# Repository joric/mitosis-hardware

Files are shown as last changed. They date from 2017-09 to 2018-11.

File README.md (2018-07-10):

Kicad Mitosis
=============

A port of original Mitosis converted with [altium2kicad](https://github.com/thesourcerer8/altium2kicad).

Disclaimer
----------

* hanya - files taken from [here](https://github.com/hanya/mitosis-hardware/tree/kicad) (with a working net), this is the most accurate
* default - cleaned up autoconverted version, should be ready for export
* big-pads - wider pads for YJ-14015 (still a bit unfinished check pads carefully!)
* autoconverted - raw autoconverted board (misplaced labels, messed up outlines, etc.)
* interphase - KiCad files taken from [here](https://github.com/Durburz/interphase) (Mitosis with a little bit more keys), see [reddit][interphase]
* orthrus - KiCad files taken from [here](https://github.com/bezmi/orthrus) (great Atreus62/Mitosis crossover by bezmi), see [reddit][orthrus]

Converting
----------

Apply .pl scripts then delete all unnecessary Edge.Cuts (such as 10x10 cm outline).

Remove board outline from Dwgs.User.

All footprint texts made invisible ("Switch", "NRF51822", etc. - they weren't in the gerbers).

Battery footprint and mitosis branding will appear misplaced, so move them down.

Check results in 3D viewer against the original gerber.

Editing
-------

To make bigger nrf51 pads, use select - Edit All Pads, set width to 2.5 mm and apply for all.

Exporting
---------

Use File-Plot command to export gerber files.

Check F.Cu, B.Cu, B.Paste, F.Paste, B.Silk, F.Silk and the Edge.Cuts layers, and also Dwgs.User.

Do not check Exclude PCB edge layer from other layers.

Then export Drill file, use Gerber in the Format section and check Minimal header.

References
----------

* [Acrylic case friendly mod (Altium)](https://github.com/YCF/mitosis-hardware-mod)
* [Hanya's port with a working net (KiCad)](https://github.com/hanya/mitosis-hardware)
* [A mod with battery between the switches (video)](https://www.reddit.com/r/MechanicalKeyboards/comments/6tcctx/new_buildmitosisplusthank_you_reverse_bias/dlk3rg7/)
* [Interphase mod with more keys](https://github.com/Durburz/interphase)
* [Orthrus - wireless split, 56 keys, based on Mitosis and Atreus](https://github.com/bezmi/orthrus)

[orthrus]: https://www.reddit.com/r/MechanicalKeyboards/comments/8txry7/orthrus_wireless_split_56_keys_based_on_mitosis
[interphase]: https://www.reddit.com/r/MechanicalKeyboards/comments/7ggeww/photos_interphase_finished_my_prototype/

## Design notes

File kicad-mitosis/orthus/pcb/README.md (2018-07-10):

# PCB

PCB design files and gerbers for the orthrus keyboard. See the [mitosis build log](https://imgur.com/a/mwTFj#JtzXTCD) for an overview of how to put this together.

There are a couple of minor differences. For example, for the programming header, my right angle connector footprint is too far in from the edge of the PCB, which resulted in the particular right angle headers I had not being reachable. I compromised by just using straight headers that go through the holes in the top (switch plate) pcb. It works just fine and the header is optional anyway. You could just as well solder temporary wires, program, then desolder before final assembly.

For the foam base, I did not have access to a lasercutter, so I cut a cloth mouse pad to size (including a cutout for the module on the bottom), cut all of the switch pins flush to the bottom of the PCB and hot glued the mousepad bits to the bottom. It is a little bumpy if you feel the bottom of the keyboard, but the typing feel is not compromised. Make sure you put tape on the module to avoid shorts!

For the receiver, I use the [mitosis receiver PCB](https://github.com/reversebias/mitosis-hardware). You can look at the BOM there (adjusting for extra switches, etc). I designed the PCBs to use the cheaper black nrf modules from aliexpress (Yj-14015), which are slightly smaller than the official waveshare module. For the receiver I had a legitimate waveshare module (blue) laying around, so I just used that, but soldering a Yj-14015 module to the receiver PCB can be very tricky. Feel free to extend the mitosis receiver pads and submit a pull request.

Make sure the PCB fab house can do 0.8mm slots. I've got mine manufactured from JLCPCB and the PCBs came out perfect.

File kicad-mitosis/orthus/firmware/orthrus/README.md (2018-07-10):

# Mitosis Keyboard Firmware

This branch adds YJ-14015 and IAR support.

mitosis-mjt (https://www.youtube.com/watch?v=hMlQvZNmCc8)

It also makes use of the keyswitch board LED (it blinks two times on powering up to indicate that firmware works).

I'm using [modified QMK firmware](https://github.com/joric/qmk_firmware/blob/mitosis-joric/keyboards/mitosis/mitosis.c) (with mitosis-MJT keymap) that adds LED startup sequence to the receiver as well.

## Hardware

* [ST-LINK/V2](http://www.ebay.com/itm/ST-Link-V2-Programming-Unit-mini-STM8-STM32-Emulator-Downloader-M89-Top-/331803020521) (OpenOCD-compatible debugger/programmer)
* [YJ-14015](https://www.aliexpress.com/item/Core51822-BLE-4-0-Bluetooth-2-4G-Wireless-Module-NRF51822-Antenna-Board-For-ULP-SPI-I2C/32832872640.html) (nRF51822-module, 32-bit ARM Cortex M0, 128kB flash + 32kB RAM)
* PCB gerbers I used in this build: https://github.com/reversebias/mitosis-hardware

I've also collected a few Kicad ports from Altium: https://github.com/joric/mitosis-hardware/tree/joric_kicad

## Software

* [IAR 7.50.2 for ARM](https://www.iar.com/) (IDE that includes a C/C++ compiler)
* [nRF5_SDK_11](https://developer.nordicsemi.com/nRF5_SDK/) (nRF51/52 toolchain)
* [OpenOCD g73b676c](http://www.freddiechopin.info/en/download/category/10-openocd-dev/) (embedded debugger for Windows 10)
* [WinAVR 20100110](https://sourceforge.net/projects/winavr/) (firmware tools for AVR MCU)

## IAR support

Original build used blue Waveshare Core51822 (B)
modules ([$6.99](http://www.waveshare.com/core51822-b.htm)), but aliexpress has slightly smaller black YJ-14015
modules that are also much cheaper (about $3.50), you can find them on Aliexpress or [eBay](http://www.ebay.com/itm/BLE4-0-Bluetooth-2-4GHz-Wireless-Module-NRF51822-Board-Core51822-B-/282575577879).
It seems like stock firmware that works on Core51822 (B), doesn't work on YJ-14015 at all (update, already works, see https://github.com/reversebias/mitosis/pull/7).
You can build a working firmware in IAR, using provided project (open .eww, run build, that's all).
You may also use precompiled firmware from the `precompiled_iar` folder.

## GCC support

This repository now supports GCC for YJ-14015 as well, so there's no need for IAR.
Use GCC-prebuild firmware from the precompiled folder or apply this diff https://github.com/reversebias/mitosis/pull/7
(update: it's already merged into upstream).

## nRF51 Firmware

This firmware is used for the nRF51 modules on the keyboard halves and the receiver.

### Precompiled nRF51 Firmware

This precompiled firmware features YJ-14015 support and status LEDs support.

* left half: [precompiled-basic-left.hex](https://raw.githubusercontent.com/joric/mitosis/devel/precompiled_iar/precompiled-basic-left.hex)
* right half: [precompiled-basic-right.hex](https://raw.githubusercontent.com/joric/mitosis/devel/precompiled_iar/precompiled-basic-right.hex)
* receiver: [precompiled-basic-receiver.hex](https://raw.githubusercontent.com/joric/mitosis/devel/precompiled_iar/precompiled-basic-receiver.hex)

### Uploading nRF51 Firmware

To flash nRF modules, connect ST-LINK/V2 to the module programming pins (SWCLK, SWDIO, GND, 3.3V - top to bottom) and run this batch (windows 10):

```
@echo off
set path=C:\SDK\openocd-0.10.0-dev-00247-g73b676c\bin-x64;%path%
set file=%~dp0custom\iar\_build\nrf51822_xxac.hex
openocd ^
-f interface/stlink-v2.cfg ^
-f target/nrf51.cfg ^
-c init ^
-c "reset halt" ^
-c "flash write_image erase %file:\=/%" ^
-c "reset" ^
-c exit

```

### Building nRF51 Firmware

I am using Windows 10 and Windows Subsystem for Linux (WSL) for everything.

Building nRF firmware with GCC:

```
cd nRF5_SDK_11
git clone https://github.com/joric/mitosis
sudo apt install openocd gcc-arm-none-eabi
(edit /components/toolchain/gcc/Makefile.posix, set GNU_INSTALL_ROOT := /usr/)
sudo cp mitosis/49-stlinkv2.rules /etc/udev/rules.d/
cd mitosis
git checkout devel
cd mitosis-keyboard-basic/custom/armgcc
make

```

## QMK Firmware

This firmware is used for the Arduino Pro Micro on the keyboard receiver.

### Precompiled QMK Firmware

First of all, check [QMK repository](https://github.com/qmk/qmk_firmware/tree/master/keyboards/mitosis/keymaps) maybe your keymap is already merged.

* mitosis-default (original) from /u/reverse_bias: [kle](http://www.keyboard-layout-editor.com/#/gists/f89d2ff79b72e920939b), [keymap.c](https://github.com/qmk/qmk_firmware/blob/master/keyboards/mitosis/keymaps/default/keymap.c), [firmware](https://raw.githubusercontent.com/joric/qmk_firmware/mitosis-joric/precompiled/mitosis_default.hex), [pic](http://i.imgur.com/Ioh0Iix.png)
* mitosis-qwerty (qwerty layout) from /u/runninghack: [kle](http://www.keyboard-layout-editor.com/#/gists/acec41432b5ce0eb341d88245a20d9da), [keymap.c](https://github.com/runninghack/qmk_firmware/blob/master/keyboards/mitosis/keymaps/qwerty/keymap.c), [firmware](https://raw.githubusercontent.com/joric/qmk_firmware/mitosis-joric/precompiled/mitosis_qwerty.hex), [pic](https://i.imgur.com/Jt0lTWt.png)
* mitosis-mjt (qwerty layout) from /u/kaybeerry: [kle](http://www.keyboard-layout-editor.com/#/gists/e213fec721cb035614cef401cd6750d6), [keymap.c](https://github.com/mterhar/qmk_firmware/blob/master/keyboards/mitosis/keymaps/mjt/keymap.c), [firmware](https://raw.githubusercontent.com/joric/qmk_firmware/mitosis-joric/precompiled/mitosis_mjt.hex), [pic](https://i.imgur.com/BiKsnIV.png)
* mitosis-carvac_dv (qwerty layout) by /u/Carvac: [keymap.c](https://github.com/CarVac/qmk_firmware/blob/master/keyboards/mitosis/keymaps/carvac_dv/keymap.c)
* mitosis-workman (workman layout) by /u/mloffer: [kle](http://www.keyboard-layout-editor.com/#/gists/db73d647ad8a67c9654a4daeab0e0873), [keymap.c](https://github.com/mloffer/mitosis-workman)
* mitosis-atreus (atreus layout) from /u/iamjoric: [kle](http://www.keyboard-layout-editor.com/#/gists/e1b26b86c4e024d2f4f3185e5b769a00), [keymap.c](https://github.com/joric/qmk_firmware/blob/mitosis-joric/keyboards/mitosis/keymaps/atreus/keymap.c), [firmware](https://raw.githubusercontent.com/joric/qmk_firmware/mitosis-joric/precompiled/mitosis_atreus.hex)
* mitosis-joric (experimental) from /u/iamjoric: [kle](http://www.keyboard-layout-editor.com/#/gists/3f5dd1c848bb9a7a723161ad5e0c8e39), [keymap.c](https://github.com/joric/qmk_firmware/blob/mitosis-joric/keyboards/mitosis/keymaps/joric/keymap.c), [firmware](https://raw.githubusercontent.com/joric/qmk_firmware/mitosis-joric/precompiled/mitosis_joric.hex)

### Uploading QMK Firmware

To flash prebuilt QMK firmware on Pro Micro, press reset button on the receiver and run the script below.
You can look up the bootloader port in device manager (e.g. COM9), it shows only for a few seconds after reset.

```
set path=C:\WinAVR-20100110\bin;%path%
avrdude -p atmega32u4 -P COM9 -c avr109  -U flash:w:mitosis_default.hex
```

### Building QMK firmware:

```
sudo apt-get install gcc-avr avr-libc
cd qmk_firmware
make mitosis-default
```

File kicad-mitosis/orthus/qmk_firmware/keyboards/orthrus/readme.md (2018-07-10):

Orthrus
=======

Keyboard Maintainer: [@bezmi](https://github.com/bezmi)
Hardware Supported: [Orthrus PCB](https://github.com/bezmi/orthrus)

Make example for this keyboard (run from root qmk_firmware directory)

    make orthrus:default:avrdude

See [build environment setup](https://docs.qmk.fm/build_environment_setup.html) then the [make instructions](https://docs.qmk.fm/make_instructions.html) for more information.

## Orthrus Notes

Files based off of the Mitosis keyboard. Uses a pro micro along with receiver PCB for wireless functionality.

Keyboard PCB design files can be found [here](https://github.com/bezmi/orthrus)
Receiver PCB is straight from the [mitosis](https://github.com/reversebias/mitosis-hardware)

Firmware for the nordic MCUs can be found [here](https://github.com/bezmi/orthrus)

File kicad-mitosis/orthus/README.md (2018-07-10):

# orthrus
56 key wireless split keyboard running on QMK. Staggered orthogonal layout

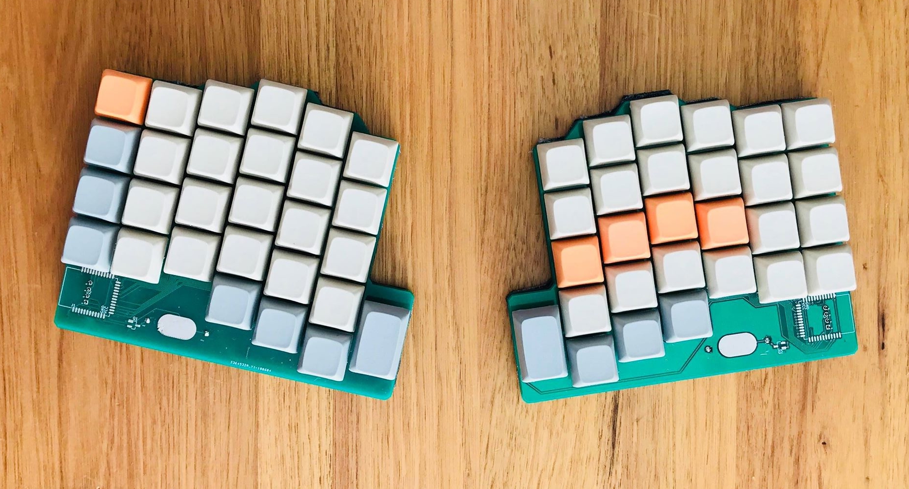
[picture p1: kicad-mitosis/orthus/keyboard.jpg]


Refer to individual folders for help on the build, raise an issue if you need any extra help :)

To use with qmk, just merge the qmk_firmware/ directory in this repository with your downloaded qmk_firmware directory

# Acknowledgements
Thanks to [@reversebias](https://github.com/reversebias) for the inspiration as well as the firmware to make this work and [@joric](https://github.com/joric) for making the firmware work with the cheaper nrf modules

Thanks to technomancy for the original 42 key [atreus](https://atreus.technomancy.us) design and profet for the [atreus62](http://shop.profetkeyboards.com/product/atreus62-keyboard) design that I have been using for quite a while.

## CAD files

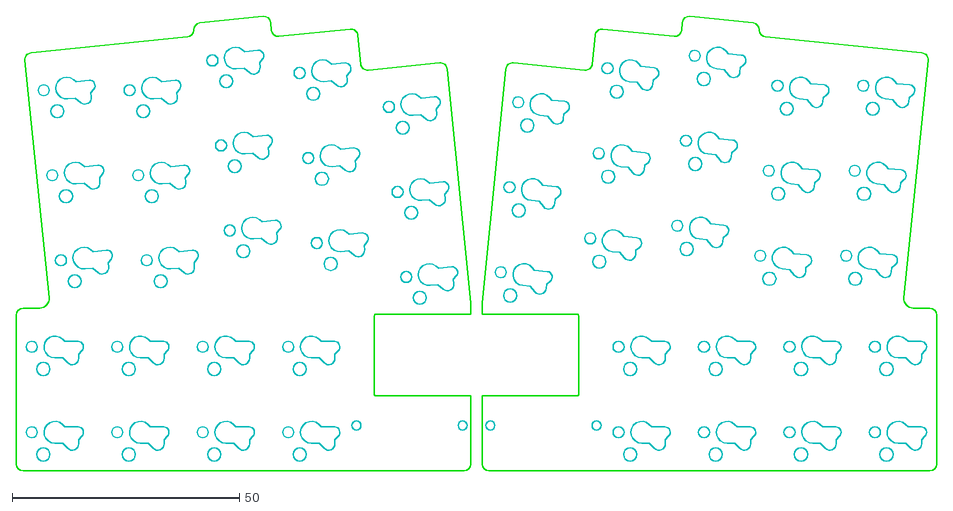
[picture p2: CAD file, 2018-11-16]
cnc/mitosis-laser.dxf
202.5 x 100.1

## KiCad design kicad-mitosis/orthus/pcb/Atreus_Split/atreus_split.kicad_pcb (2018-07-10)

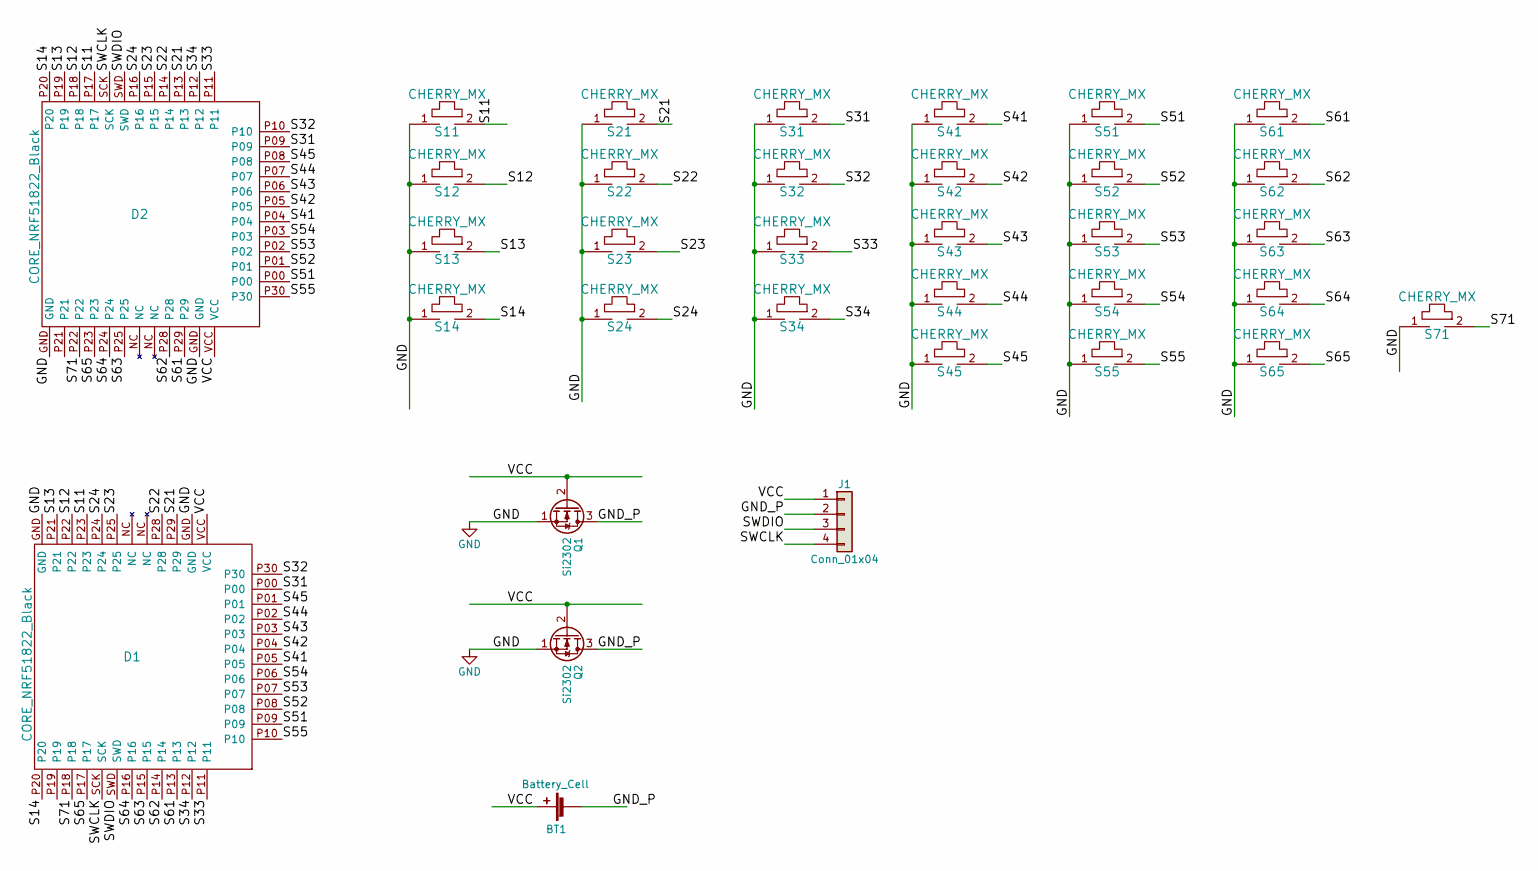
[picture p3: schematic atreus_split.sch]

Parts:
BT1: Battery_Cell; CR2032_pad
D1, D2: CORE_NRF51822_Black
J1: Conn_01x04; Pin_Header_Angled_1x04_Pitch2.54mm
Q1, Q2: Si2302; SI2302
S11, S12, S13, S14, S21, S22, S23, S24, S31, S32, S33, S34, S41, S42, S43, S44, S45, S51, S52, S53, S54, S55, S61, S62, S63, S64, S65, S71: CHERRY_MX; cherry

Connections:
/GND_P: BT1.2 (-), J1.2, Q1.3 (D), Q2.3 (D)
/S11: D1.P23, D2.P17, S11.2
/S12: D1.P22, D2.P18, S12.2
/S13: D1.P21, D2.P19, S13.2
/S14: D1.P20, D2.P20, S14.2
/S21: D1.P29, D2.P13, S21.2
/S22: D1.P28, D2.P14, S22.2
/S23: D1.P25, D2.P15, S23.2
/S24: D1.P24, D2.P16, S24.2
/S31: D1.P00, D2.P09, S31.2
/S32: D1.P30, D2.P10, S32.2
/S33: D1.P11, D2.P11, S33.2
/S34: D1.P12, D2.P12, S34.2
/S41: D1.P05, D2.P04, S41.2
/S42: D1.P04, D2.P05, S42.2
/S43: D1.P03, D2.P06, S43.2
/S44: D1.P02, D2.P07, S44.2
/S45: D1.P01, D2.P08, S45.2
/S51: D1.P09, D2.P00, S51.2
/S52: D1.P08, D2.P01, S52.2
/S53: D1.P07, D2.P02, S53.2
/S54: D1.P06, D2.P03, S54.2
/S55: D1.P10, D2.P30, S55.2
/S61: D1.P13, D2.P29, S61.2
/S62: D1.P14, D2.P28, S62.2
/S63: D1.P15, D2.P25, S63.2
/S64: D1.P16, D2.P24, S64.2
/S65: D1.P17, D2.P23, S65.2
/S71: D1.P18, D2.P22, S71.2
/SWCLK: D1.SCK, D2.SCK, J1.4
/SWDIO: D1.SWD, D2.SWD, J1.3
/VCC: BT1.1 (+), D1.VCC, D2.VCC, J1.1, Q1.2 (G), Q2.2 (G)
GND: D1.GND, D2.GND, Q1.1 (S), Q2.1 (S), S11.1, S12.1, S13.1, S14.1, S21.1, S22.1, S23.1, S24.1, S31.1, S32.1, S33.1, S34.1, S41.1, S42.1, S43.1, S44.1, S45.1, S51.1, S52.1, S53.1, S54.1, S55.1, S61.1, S62.1, S63.1, S64.1, S65.1, S71.1

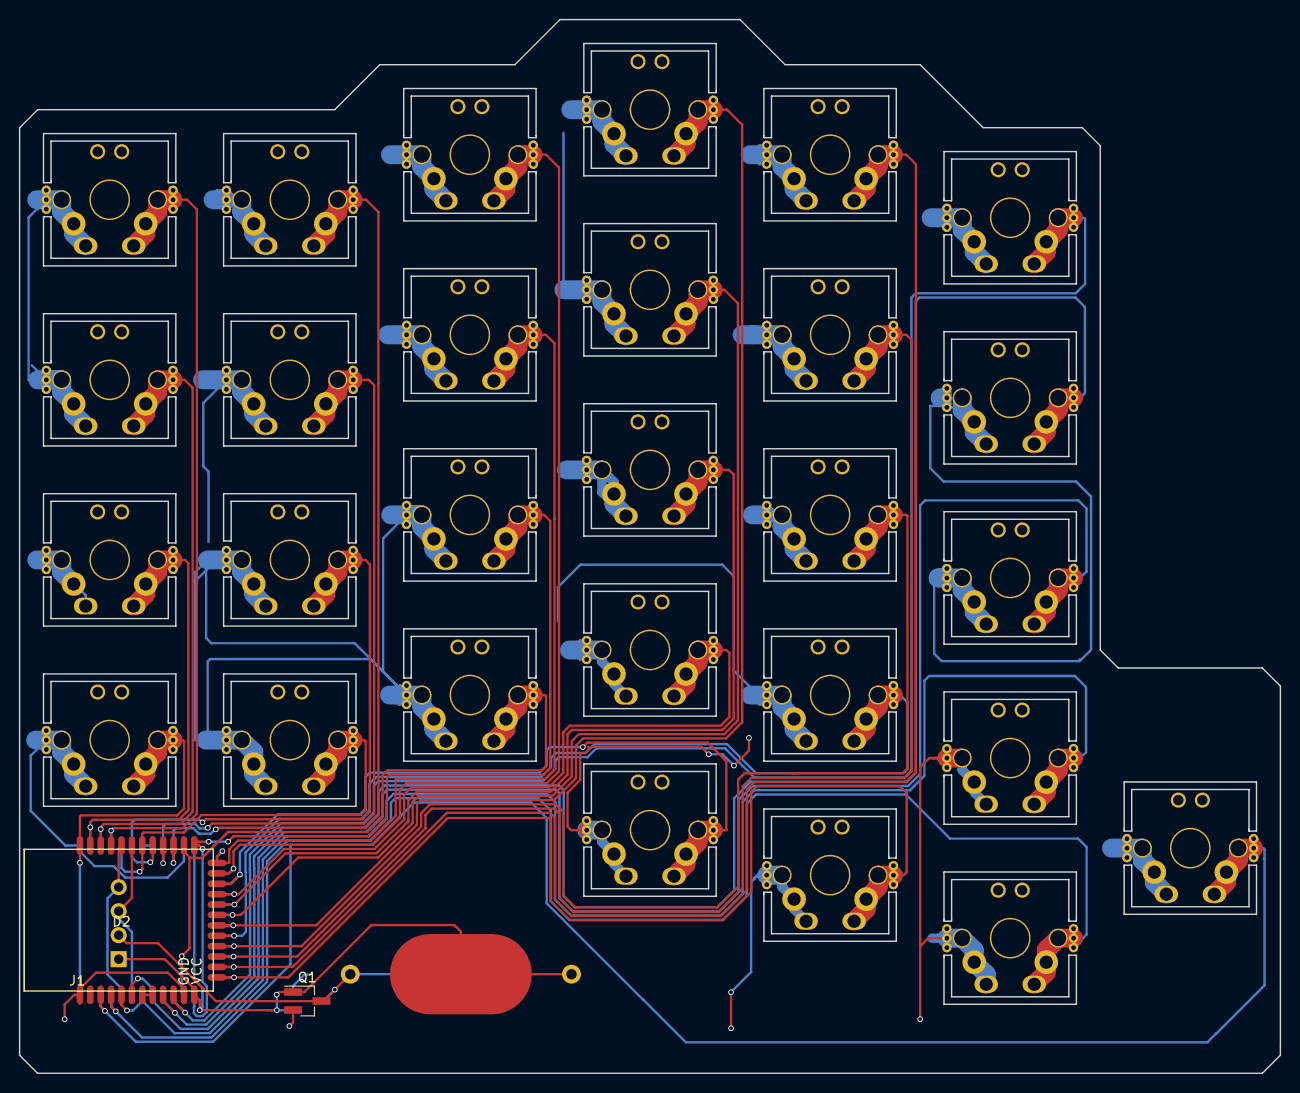
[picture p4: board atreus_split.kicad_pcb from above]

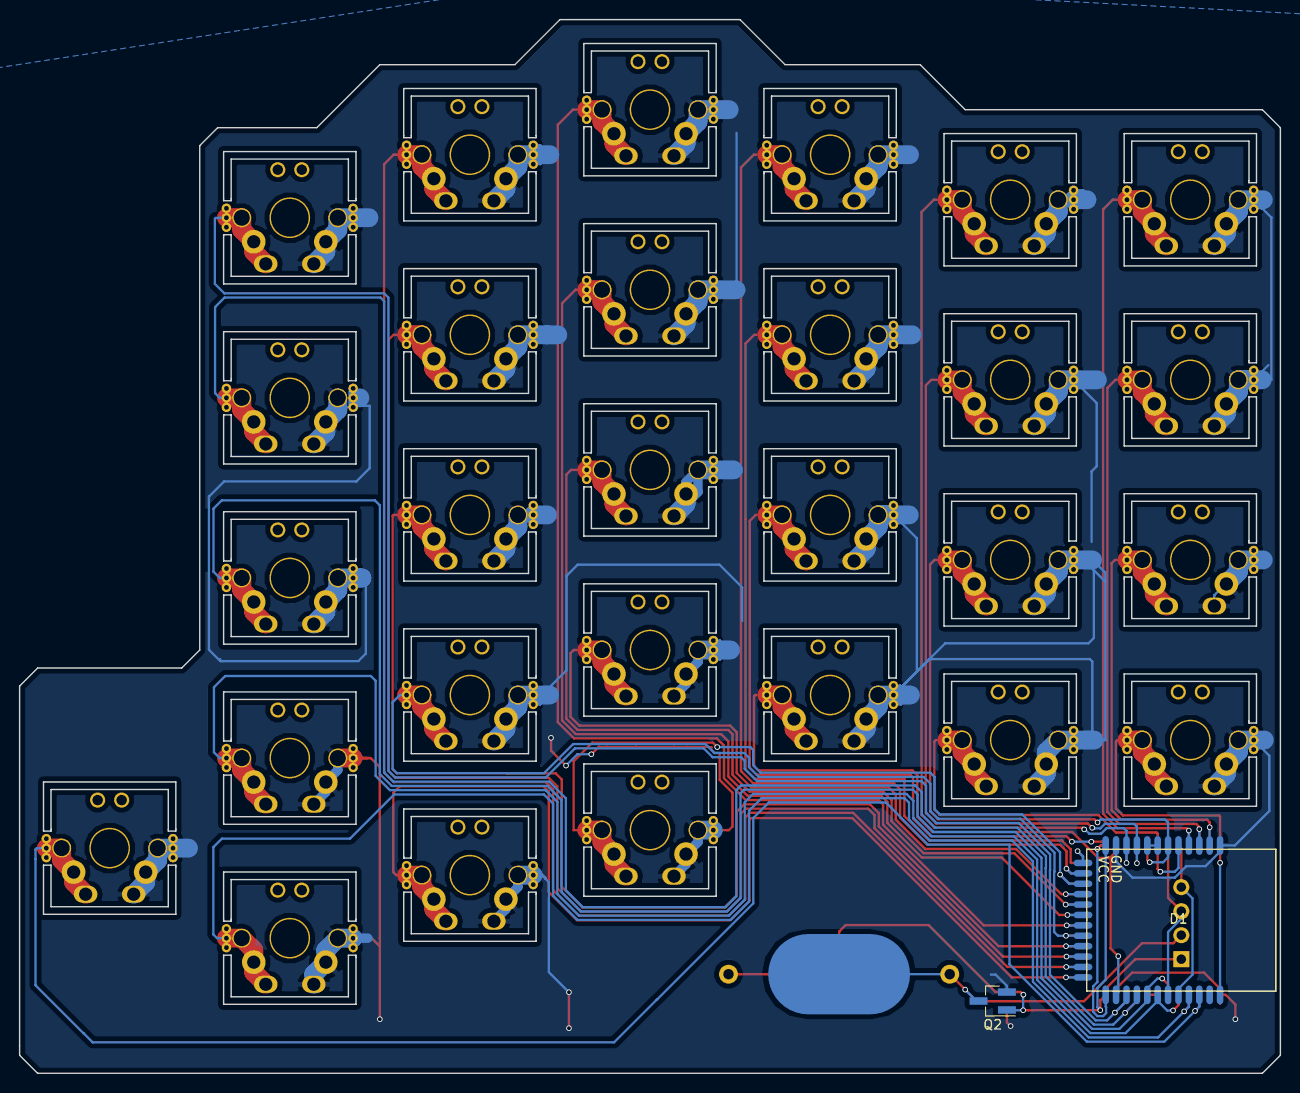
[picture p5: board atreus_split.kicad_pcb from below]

Board: 2 copper layers, 133.4 x 111.4 mm, 34 parts (2 on the bottom side), 33 nets.

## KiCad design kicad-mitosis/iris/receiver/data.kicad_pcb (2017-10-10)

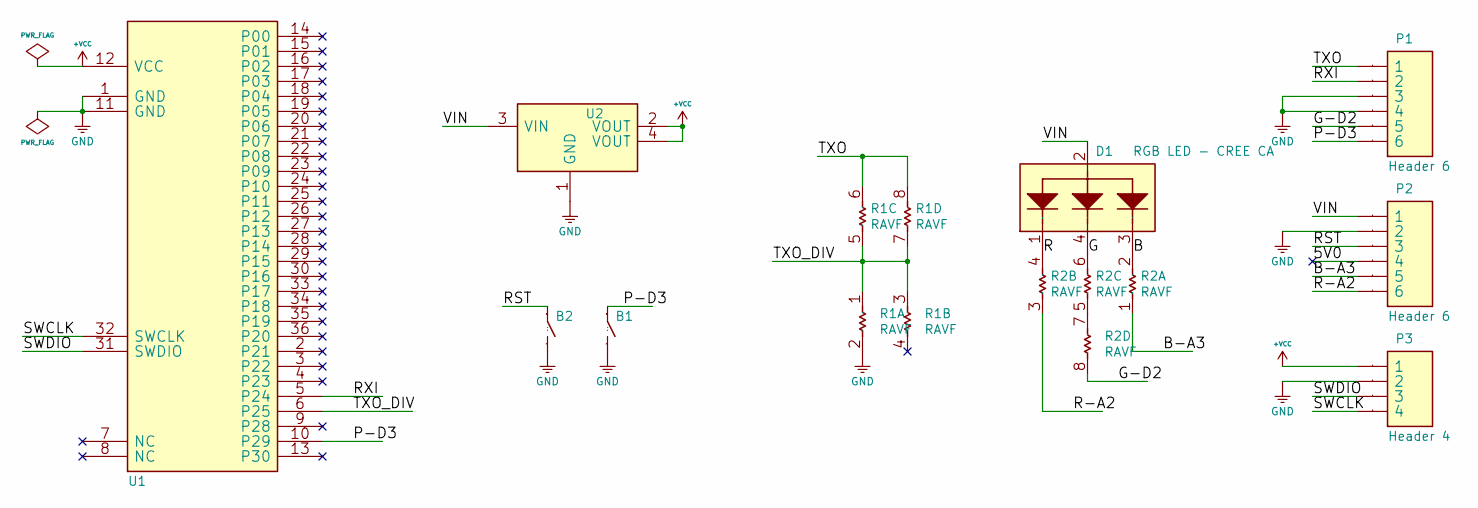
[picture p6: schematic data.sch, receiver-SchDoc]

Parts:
B1, B2: TACTILE_BUTTON
D1: RGB LED - CREE CA; PLCC4-RGBLED
P1, P2: Header 6; HDR1X6
P3: Header 4; HDR1X4
R1, R2: RAVF; 1206_quad_res
U1: Core51822B
U2: SOT230P700X180-4N

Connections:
/5V0: P2.4
/B: D1.3 (B), R2.2
/B-A3: P2.5, R2.1
/G: D1.4 (G), R2.6 (2)
/G-D2: P1.5, R2.8 (2)
/P-D3: B1.1, P1.6, U1.10 (P29)
/R: D1.1 (R), R2.4 (2)
/R-A2: P2.6, R2.3 (1)
/RST: B2.1, P2.3
/RXI: P1.2, U1.5 (P24)
/SWCLK: P3.4, U1.32 (SWCLK)
/SWDIO: P3.3, U1.31 (SWDIO)
/TXO: P1.1, R1.6 (2), R1.8 (2)
/TXO_DIV: R1.1, R1.3 (1), R1.5 (1), R1.7 (1), U1.6 (P25)
/VIN: D1.2 (CA), P2.1, U2.3 (VIN)
GND: B1.2, B2.2, P1.3, P1.4, P2.2, P3.2, R1.2, U1.1 (GND), U1.11 (GND), U2.1 (GND)
unnamed: R2.5 (1), R2.7 (1)
VCC: P3.1, U1.12 (VCC), U2.2 (VOUT), U2.4 (VOUT)

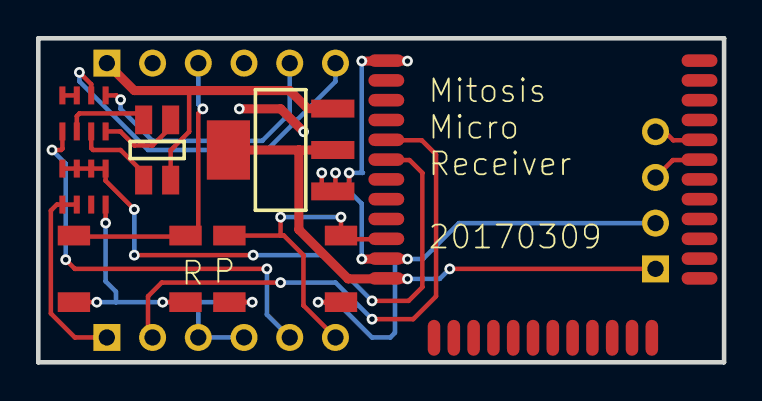
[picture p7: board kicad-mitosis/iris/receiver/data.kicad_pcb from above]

Board: 2 copper layers, 38.1 x 18.0 mm, 10 parts (1 on the bottom side), 17 nets.

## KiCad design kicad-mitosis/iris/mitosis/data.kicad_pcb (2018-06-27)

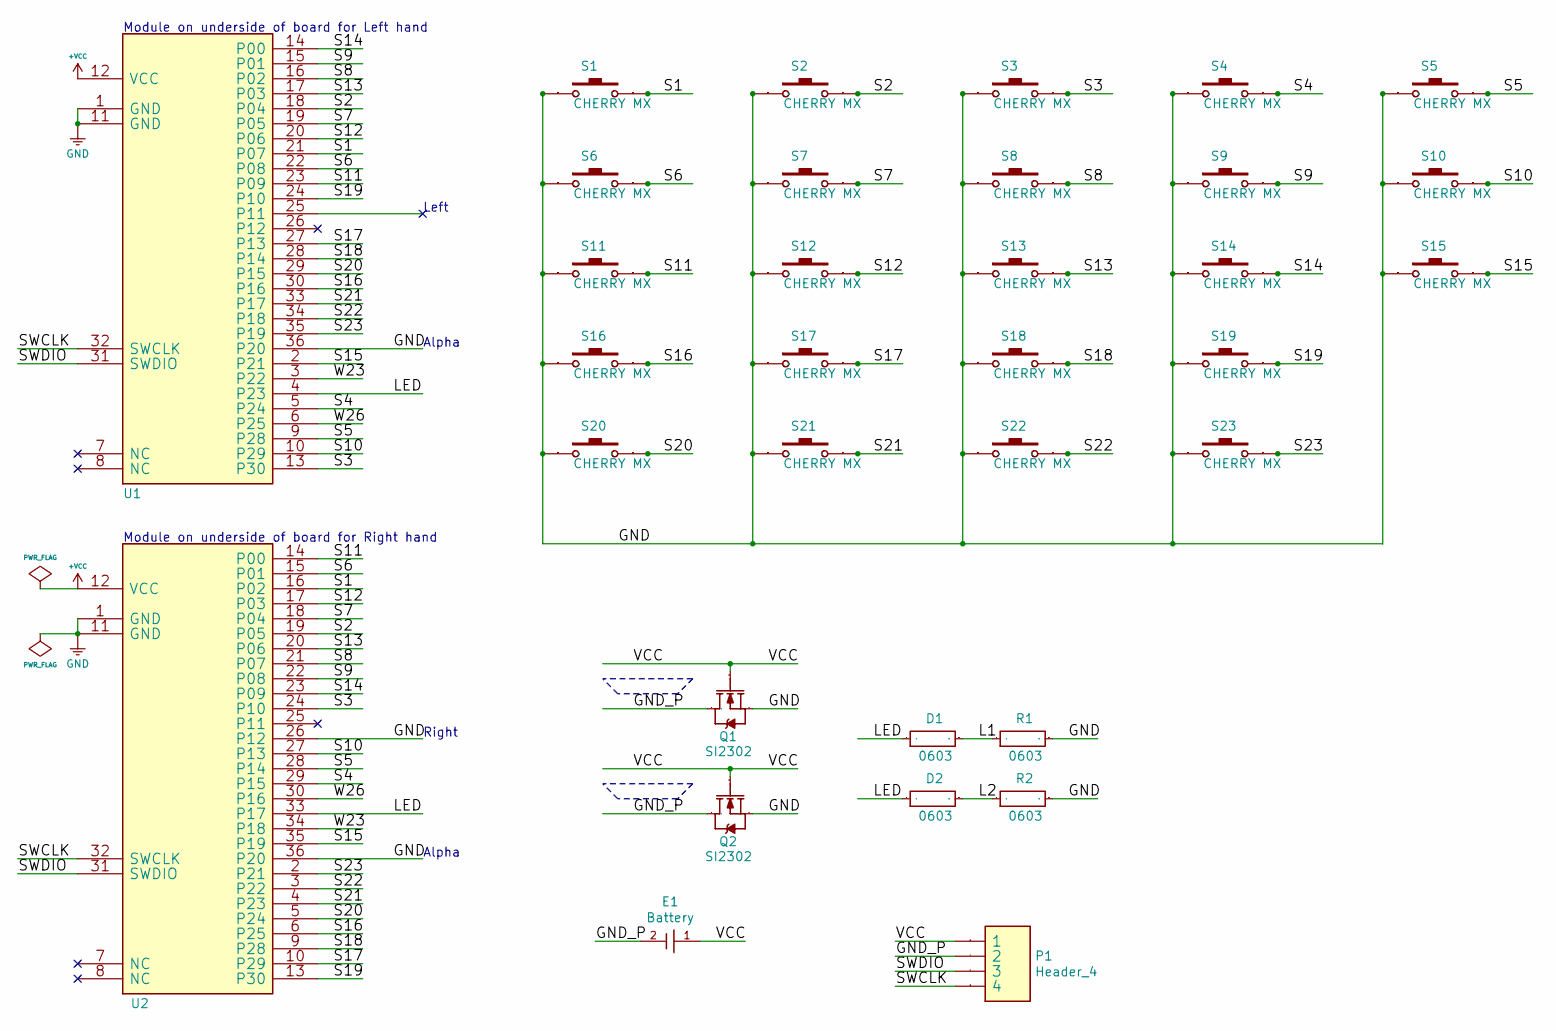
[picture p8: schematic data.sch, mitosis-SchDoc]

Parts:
D1, D2: 0603; RESC2012X06N
E1: Battery; CR2032_pad
P1: Header_4; HDR1X4
Q1, Q2: SI2302; SOT-23
R1, R2: 0603; RESC2012X06N
S1, S2, S3, S4, S5, S6, S7, S8, S9, S10, S11, S12, S13, S14, S15: CHERRY MX; cherry_angled
S16, S17, S18, S19, S20, S21, S22, S23: CHERRY MX; cherry
U1, U2: Core51822B

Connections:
/GND_P: E1.2 (M), P1.2, Q1.3 (D), Q2.3 (D)
/L1: D1.1, R1.2
/L2: D2.1, R2.2
/LED: D1.2, D2.2, U1.4 (P23), U2.33 (P17)
/S1: S1.2, S1.4, S1.6, S1.8, S1.10, S1.12, U1.21 (P07), U2.16 (P02)
/S2: S2.2, S2.4, S2.6, S2.8, S2.10, S2.12, U1.18 (P04), U2.19 (P05)
/S3: S3.2, S3.4, S3.6, S3.8, S3.10, S3.12, U1.13 (P30), U2.24 (P10)
/S4: S4.2, S4.4, S4.6, S4.8, S4.10, S4.12, U1.5 (P24), U2.29 (P15)
/S5: S5.2, S5.4, S5.6, S5.8, S5.10, S5.12, U1.9 (P28), U2.28 (P14)
/S6: S6.2, S6.4, S6.6, S6.8, S6.10, S6.12, U1.22 (P08), U2.15 (P01)
/S7: S7.2, S7.4, S7.6, S7.8, S7.10, S7.12, U1.19 (P05), U2.18 (P04)
/S8: S8.2, S8.4, S8.6, S8.8, S8.10, S8.12, U1.16 (P02), U2.21 (P07)
/S9: S9.2, S9.4, S9.6, S9.8, S9.10, S9.12, U1.15 (P01), U2.22 (P08)
/S10: S10.2, S10.4, S10.6, S10.8, S10.10, S10.12, U1.10 (P29), U2.27 (P13)
/S11: S11.2, S11.4, S11.6, S11.8, S11.10, S11.12, U1.23 (P09), U2.14 (P00)
/S12: S12.2, S12.4, S12.6, S12.8, S12.10, S12.12, U1.20 (P06), U2.17 (P03)
/S13: S13.2, S13.4, S13.6, S13.8, S13.10, S13.12, U1.17 (P03), U2.20 (P06)
/S14: S14.2, S14.4, S14.6, S14.8, S14.10, S14.12, U1.14 (P00), U2.23 (P09)
/S15: S15.2, S15.4, S15.6, S15.8, S15.10, S15.12, U1.2 (P21), U2.35 (P19)
/S16: S16.2, S16.4, S16.6, S16.8, S16.10, S16.12, U1.30 (P16), U2.6 (P25)
/S17: S17.2, S17.4, S17.6, S17.8, S17.10, S17.12, U1.27 (P13), U2.10 (P29)
/S18: S18.2, S18.4, S18.6, S18.8, S18.10, S18.12, U1.28 (P14), U2.9 (P28)
/S19: S19.2, S19.4, S19.6, S19.8, S19.10, S19.12, U1.24 (P10), U2.13 (P30)
/S20: S20.2, S20.4, S20.6, S20.8, S20.10, S20.12, U1.29 (P15), U2.5 (P24)
/S21: S21.2, S21.4, S21.6, S21.8, S21.10, S21.12, U1.33 (P17), U2.4 (P23)
/S22: S22.2, S22.4, S22.6, S22.8, S22.10, S22.12, U1.34 (P18), U2.3 (P22)
/S23: S23.2, S23.4, S23.6, S23.8, S23.10, S23.12, U1.35 (P19), U2.2 (P21)
/SWCLK: P1.4, U1.32 (SWCLK), U2.32 (SWCLK)
/SWDIO: P1.3, U1.31 (SWDIO), U2.31 (SWDIO)
/W23: U1.3 (P22), U2.34 (P18)
/W26: U1.6 (P25), U2.30 (P16)
GND: Q1.2 (S), Q2.2 (S), R1.1, R2.1, S1.1, S1.3, S1.5, S1.7, S1.9, S1.11, S2.1, S2.3, S2.5, S2.7, S2.9, S2.11, S3.1, S3.3, S3.5, S3.7, S3.9, S3.11, S4.1, S4.3, S4.5, S4.7, S4.9, S4.11, S5.1, S5.3, S5.5, S5.7, S5.9, S5.11, S6.1, S6.3, S6.5, S6.7, S6.9, S6.11, S7.1, S7.3, S7.5, S7.7, S7.9, S7.11, S8.1, S8.3, S8.5, S8.7, S8.9, S8.11, S9.1, S9.3, S9.5, S9.7, S9.9, S9.11, S10.1, S10.3, S10.5, S10.7, S10.9, S10.11, S11.1, S11.3, S11.5, S11.7, S11.9, S11.11, S12.1, S12.3, S12.5, S12.7, S12.9, S12.11, S13.1, S13.3, S13.5, S13.7, S13.9, S13.11, S14.1, S14.3, S14.5, S14.7, S14.9, S14.11, S15.1, S15.3, S15.5, S15.7, S15.9, S15.11, S16.1, S16.3, S16.5, S16.7, S16.9, S16.11, S17.1, S17.3, S17.5, S17.7, S17.9, S17.11, S18.1, S18.3, S18.5, S18.7, S18.9, S18.11, S19.1, S19.3, S19.5, S19.7, S19.9, S19.11, S20.1, S20.3, S20.5, S20.7, S20.9, S20.11, S21.1, S21.3, S21.5, S21.7, S21.9, S21.11, S22.1, S22.3, S22.5, S22.7, S22.9, S22.11, S23.1, S23.3, S23.5, S23.7, S23.9, S23.11, U1.1 (GND), U1.11 (GND), U1.36 (P20), U2.1 (GND), U2.11 (GND), U2.26 (P12), U2.36 (P20)

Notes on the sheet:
Alpha
Right
Left
Module on underside of board for Right hand
Module on underside of board for Left hand

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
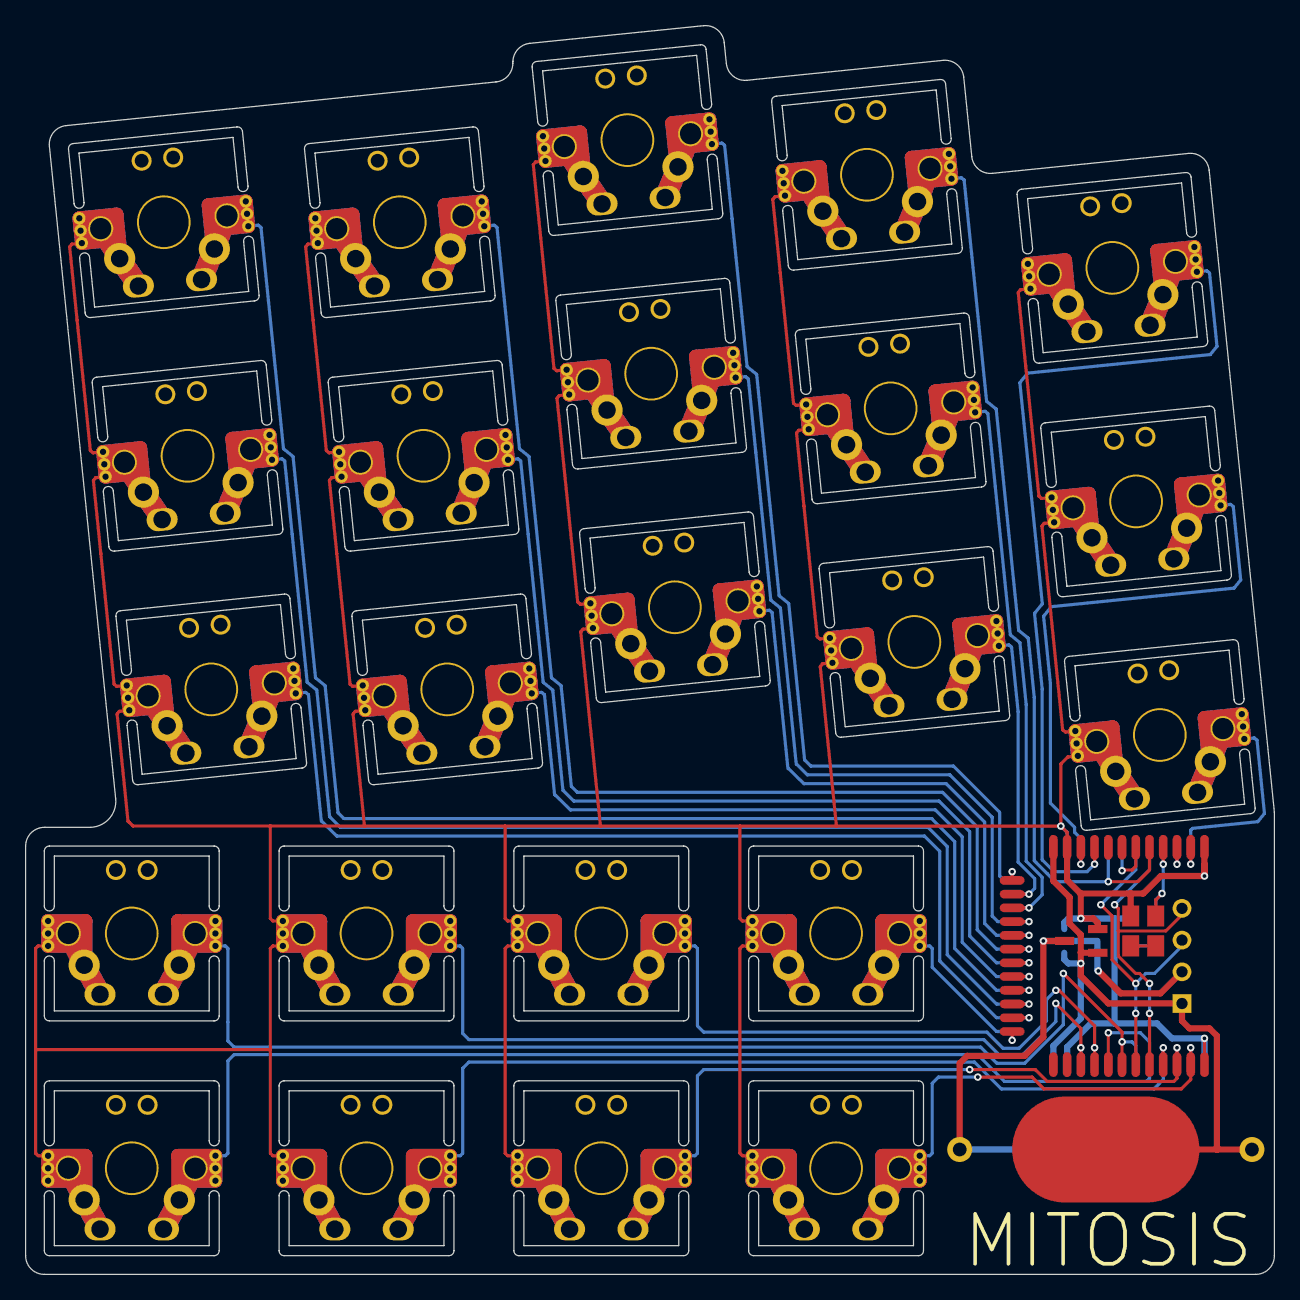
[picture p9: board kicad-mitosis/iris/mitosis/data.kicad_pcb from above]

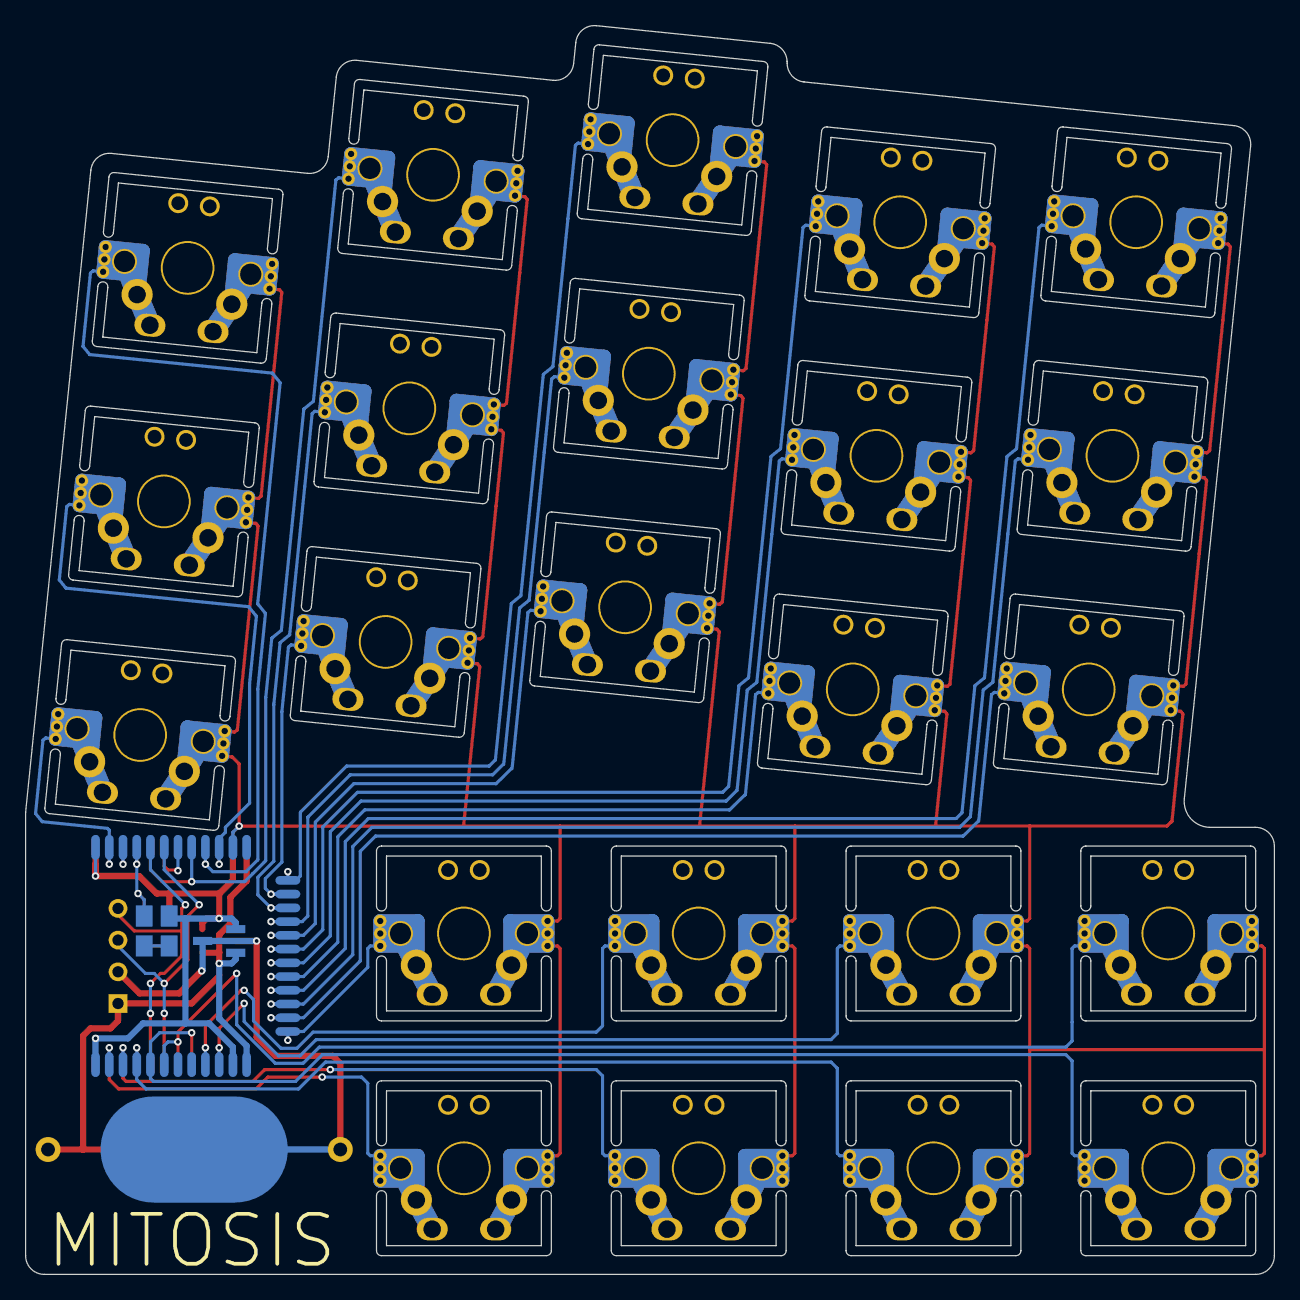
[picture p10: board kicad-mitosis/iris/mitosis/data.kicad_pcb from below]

Board: 2 copper layers, 100.0 x 100.0 mm, 33 parts (4 on the bottom side), 33 nets.

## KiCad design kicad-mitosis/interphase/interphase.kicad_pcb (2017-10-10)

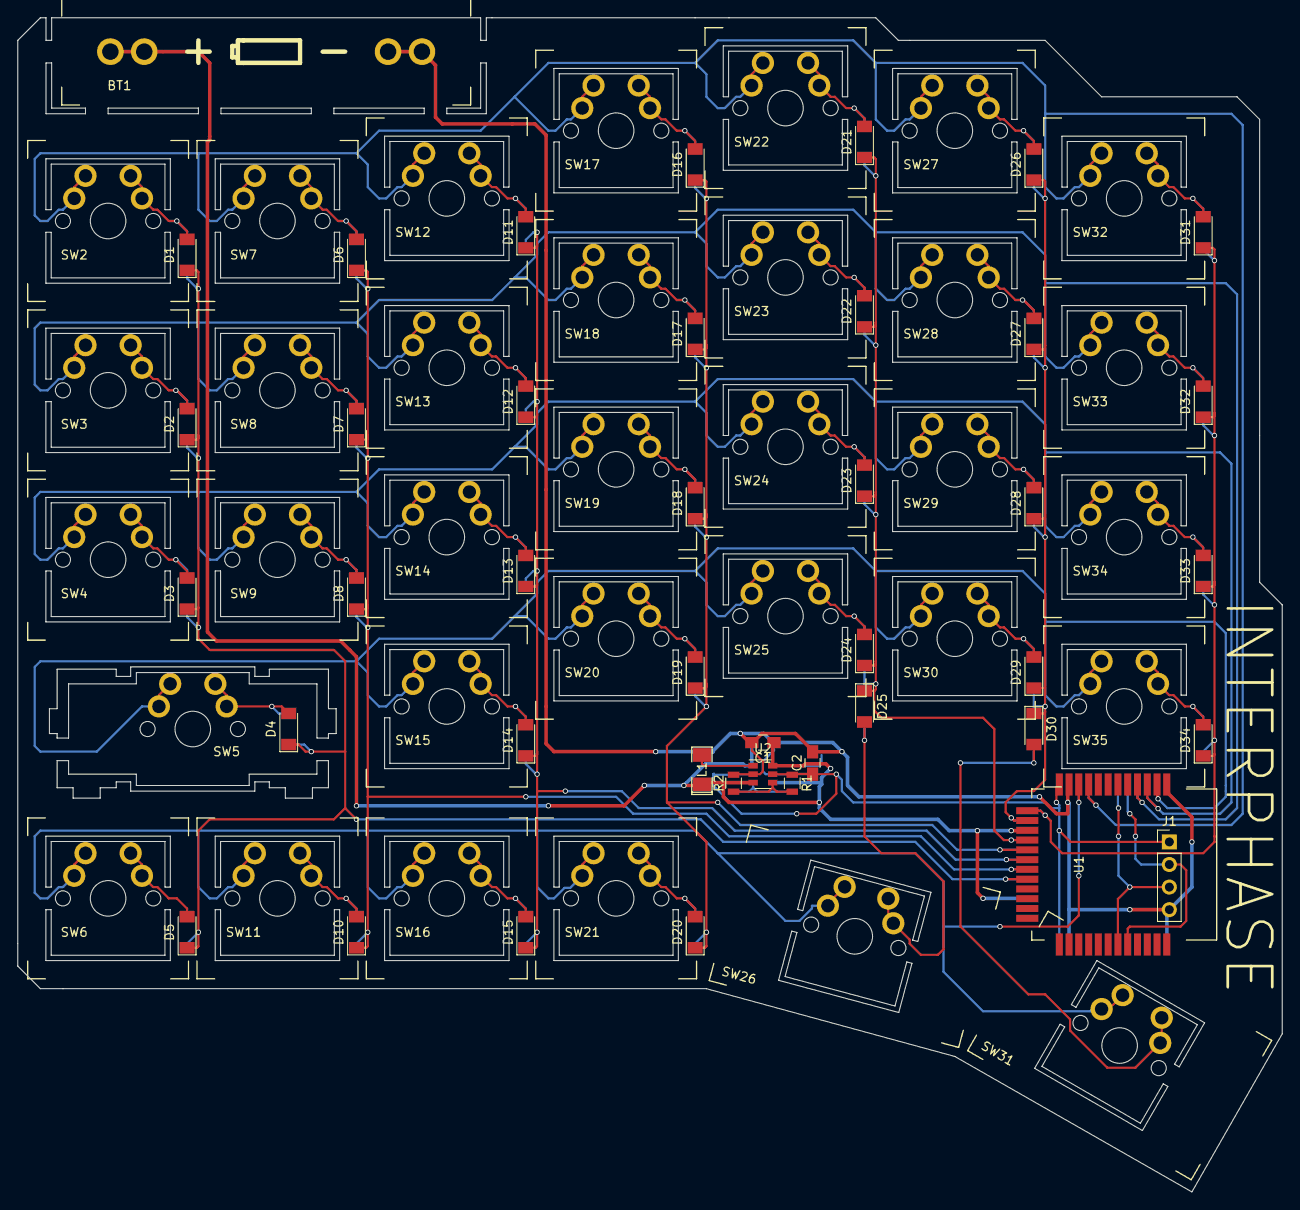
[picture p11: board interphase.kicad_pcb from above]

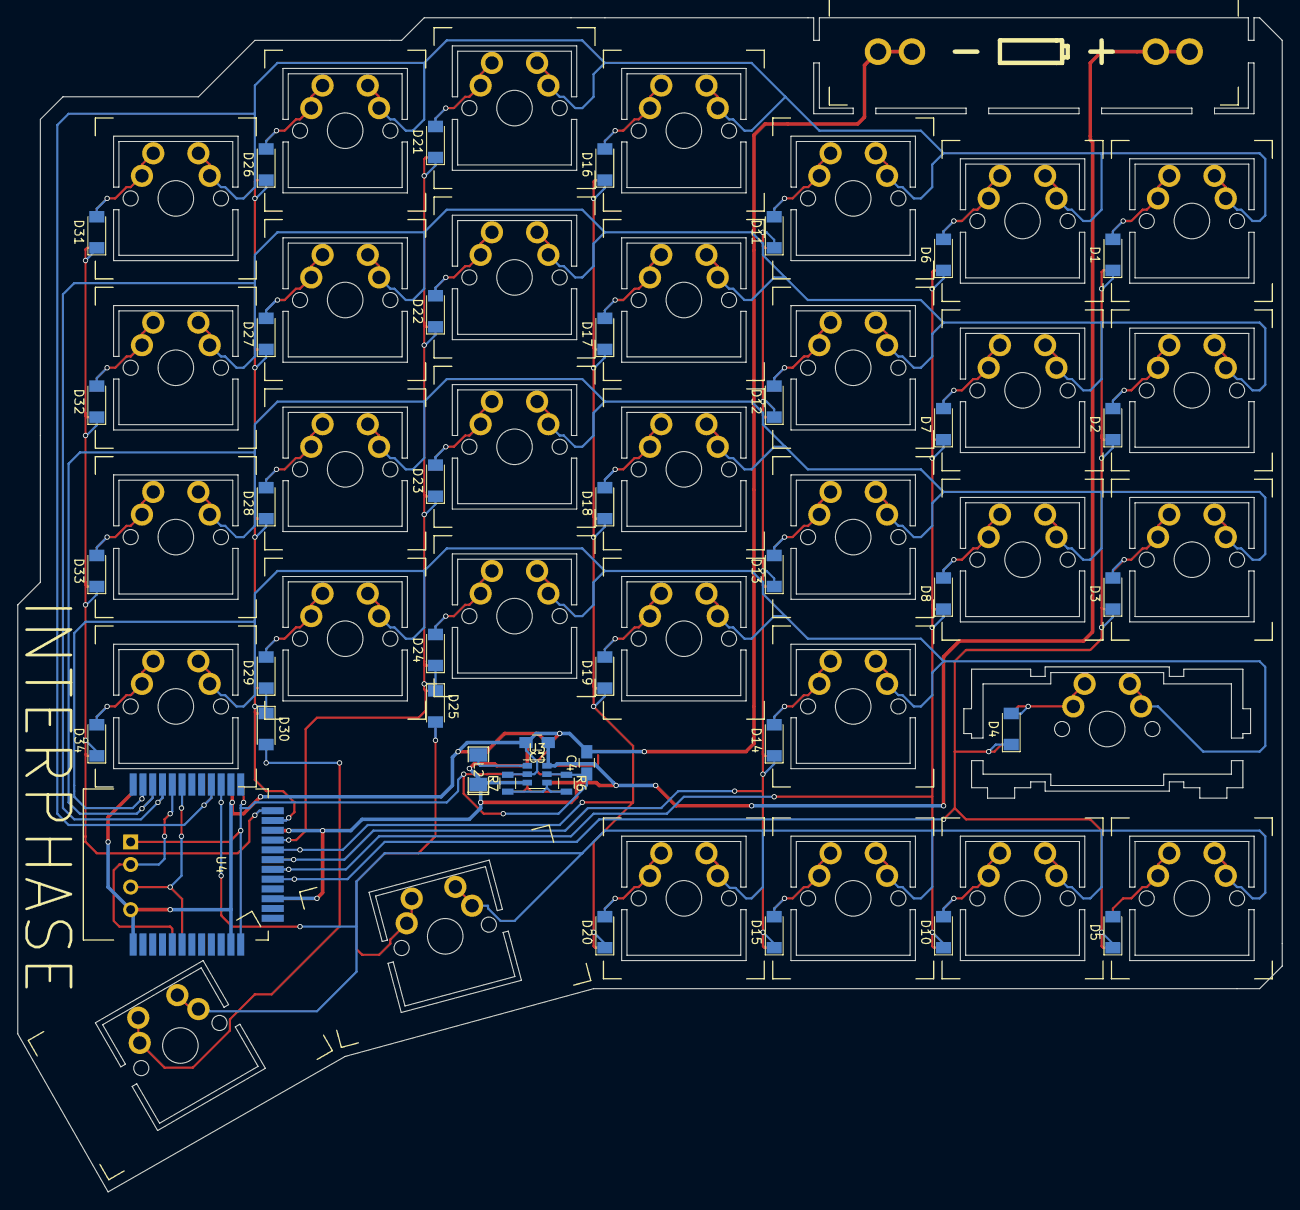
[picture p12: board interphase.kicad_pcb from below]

Board: 2 copper layers, 142.2 x 132.1 mm, 115 parts (40 on the bottom side), 54 nets.

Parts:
BT1: Battery_Cell; KEYSTONE-82_AAA_battery-clip
C1, C3: 4,7µF; C_0805_HandSoldering
C2, C4: 10µF; C_0805_HandSoldering
D1, D1#2, D2, D2#2, D3, D3#2, D4, D4#2, D5, D5#2, D6, D6#2, D7, D7#2, D8, D8#2, D10, D10#2, D11, D11#2, D12, D12#2, D13, D13#2, D14, D14#2, D15, D15#2, D16, D16#2, D17, D17#2, D18, D18#2, D19, D19#2, D20, D20#2, D21, D21#2, D22, D22#2, D23, D23#2, D24, D24#2, D25, D25#2, D26, D26#2, D27, D27#2, D28, D28#2, D29, D29#2, D30, D30#2, D31, D31#2, D32, D32#2, D33, D33#2, D34, D34#2: D; D_MiniMELF
J1: Conn_01x04_Male; Pin_Header_Straight_1x04_Pitch2.54mm
L1, L2: 4,7µH; SMD-1206_Pol
R1, R6: 536K; R_0805
R2, R7: 309K; R_0805
SW2, SW3, SW4, SW6, SW7, SW8, SW9, SW11, SW12, SW13, SW14, SW15, SW16, SW17, SW18, SW19, SW20, SW21, SW22, SW23, SW24, SW25, SW27, SW28, SW29, SW30, SW32, SW33, SW34, SW35: MOM-SPST; CHERRY-MX_double_bo_nodiode
SW5: MOM-SPST; CHERRY-MX_double_bo_2u_nodiode
SW26, SW31: MOM-SPST; CHERRY-MX_double_bo_1_5u
U1, U4: Core51822B; Core51822(B)
U2, U3: MCP1640; SOT-23-6

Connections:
+3V3: C2.1, C4.1, J1.1, R1.1, R6.1, U1.12, U2.5, U3.5, U4.12
+BATT: BT1.1, C1.1, C3.1, L1.1, L2.1, U1.15, U2.3, U2.6, U3.3, U3.6, U4.15
GND: BT1.2, C1.2, C2.2, C3.2, C4.2, J1.4, R2.2, R7.2, U1.1, U1.11, U2.2, U3.2, U4.1, U4.11
unnamed: D1.1, D1#2.1, D2.1, D2#2.1, D3.1, D3#2.1, D4.1, D4#2.1, D5.1, D5#2.1, U1.20, U4.17
unnamed: D1.2, D1#2.2, SW2.2
unnamed: D2.2, D2#2.2, SW3.2
unnamed: D3.2, D3#2.2, SW4.2
unnamed: D4.2, D4#2.2, SW5.2
unnamed: D5.2, D5#2.2, SW6.2
unnamed: D6.2, D6#2.2, SW7.2
unnamed: D7.2, D7#2.2, SW8.2
unnamed: D8.2, D8#2.2, SW9.2
unnamed: D6.1, D6#2.1, D7.1, D7#2.1, D8.1, D8#2.1, D10.1, D10#2.1, U1.19, U4.18
unnamed: D10.2, D10#2.2, SW11.2
unnamed: D11.1, D11#2.1, D12.1, D12#2.1, D13.1, D13#2.1, D14.1, D14#2.1, D15.1, D15#2.1, U1.18, U4.19
unnamed: D11.2, D11#2.2, SW12.2
unnamed: D12.2, D12#2.2, SW13.2
unnamed: D13.2, D13#2.2, SW14.2
unnamed: D14.2, D14#2.2, SW15.2
unnamed: D15.2, D15#2.2, SW16.2
unnamed: D16.1, D16#2.1, D17.1, D17#2.1, D18.1, D18#2.1, D19.1, D19#2.1, D20.1, D20#2.1, U1.17, U4.20
unnamed: D16.2, D16#2.2, SW17.2
unnamed: D17.2, D17#2.2, SW18.2
unnamed: D18.2, D18#2.2, SW19.2
unnamed: D19.2, D19#2.2, SW20.2
unnamed: D20.2, D20#2.2, SW21.2
unnamed: D21.1, D21#2.1, D22.1, D22#2.1, D23.1, D23#2.1, D24.1, D24#2.1, D25.1, D25#2.1, U1.16, U4.21
unnamed: D21.2, D21#2.2, SW22.2
unnamed: D22.2, D22#2.2, SW23.2
unnamed: D23.2, D23#2.2, SW24.2
unnamed: D24.2, D24#2.2, SW25.2
unnamed: D25.2, D25#2.2, SW26.2
unnamed: D26.1, D26#2.1, D27.1, D27#2.1, D28.1, D28#2.1, D29.1, D29#2.1, D30.1, D30#2.1, U1.14, U4.23
unnamed: D26.2, D26#2.2, SW27.2
unnamed: D27.2, D27#2.2, SW28.2
unnamed: D28.2, D28#2.2, SW29.2
unnamed: D29.2, D29#2.2, SW30.2
unnamed: D30.2, D30#2.2, SW31.2
unnamed: D31.1, D31#2.1, D32.1, D32#2.1, D33.1, D33#2.1, D34.1, D34#2.1, U1.13, U4.24
unnamed: D31.2, D31#2.2, SW32.2
unnamed: D32.2, D32#2.2, SW33.2
unnamed: D33.2, D33#2.2, SW34.2
unnamed: D34.2, D34#2.2, SW35.2
unnamed: J1.2, U1.32, U4.32
unnamed: J1.3, U1.31, U4.31
unnamed: L1.2, U2.1
unnamed: L2.2, U3.1
unnamed: R1.2, R2.1, U2.4
unnamed: R6.2, R7.1, U3.4
unnamed: SW6.1, SW11.1, SW16.1, SW21.1, SW26.1, SW31.1, U1.10, U4.27
unnamed: SW2.1, SW7.1, SW12.1, SW17.1, SW22.1, SW27.1, SW32.1, U1.9, U4.28
unnamed: SW3.1, SW8.1, SW13.1, SW18.1, SW23.1, SW28.1, SW33.1, U1.4, U4.33
unnamed: SW4.1, SW9.1, SW14.1, SW19.1, SW24.1, SW29.1, SW34.1, U1.3, U4.34
unnamed: SW5.1, SW15.1, SW20.1, SW25.1, SW30.1, SW35.1, U1.2, U4.35

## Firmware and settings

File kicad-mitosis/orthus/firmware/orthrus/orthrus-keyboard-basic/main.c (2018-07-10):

#define COMPILE_RIGHT
/*#define COMPILE_LEFT*/

#include "mitosis.h"
#include "nrf_drv_config.h"
#include "nrf_gzll.h"
#include "nrf_gpio.h"
#include "nrf_delay.h"
#include "nrf_drv_clock.h"
#include "nrf_drv_rtc.h"


/*****************************************************************************/
/** Configuration */
/*****************************************************************************/

const nrf_drv_rtc_t rtc_maint = NRF_DRV_RTC_INSTANCE(0); /**< Declaring an instance of nrf_drv_rtc for RTC0. */
const nrf_drv_rtc_t rtc_deb = NRF_DRV_RTC_INSTANCE(1); /**< Declaring an instance of nrf_drv_rtc for RTC1. */


// Define payload length
#define TX_PAYLOAD_LENGTH 4 ///< 3 byte payload length when transmitting

// Data and acknowledgement payloads
static uint8_t data_payload[TX_PAYLOAD_LENGTH];                ///< Payload to send to Host. 
static uint8_t ack_payload[NRF_GZLL_CONST_MAX_PAYLOAD_LENGTH]; ///< Placeholder for received ACK payloads from Host.

// Debounce time (dependent on tick frequency)
#define DEBOUNCE 5
#define ACTIVITY 500

// Key buffers
static uint32_t keys, keys_snapshot;
static uint32_t debounce_ticks, activity_ticks;
static volatile bool debouncing = false;

// Debug helper variables
static volatile bool init_ok, enable_ok, push_ok, pop_ok, tx_success;  

// Setup switch pins with pullups
static void gpio_config(void)
{
    nrf_gpio_cfg_sense_input(S11, NRF_GPIO_PIN_PULLUP, NRF_GPIO_PIN_SENSE_LOW);
    nrf_gpio_cfg_sense_input(S12, NRF_GPIO_PIN_PULLUP, NRF_GPIO_PIN_SENSE_LOW);
    nrf_gpio_cfg_sense_input(S13, NRF_GPIO_PIN_PULLUP, NRF_GPIO_PIN_SENSE_LOW);
    nrf_gpio_cfg_sense_input(S14, NRF_GPIO_PIN_PULLUP, NRF_GPIO_PIN_SENSE_LOW);
    nrf_gpio_cfg_sense_input(S21, NRF_GPIO_PIN_PULLUP, NRF_GPIO_PIN_SENSE_LOW);
    nrf_gpio_cfg_sense_input(S22, NRF_GPIO_PIN_PULLUP, NRF_GPIO_PIN_SENSE_LOW);
    nrf_gpio_cfg_sense_input(S23, NRF_GPIO_PIN_PULLUP, NRF_GPIO_PIN_SENSE_LOW);
    nrf_gpio_cfg_sense_input(S24, NRF_GPIO_PIN_PULLUP, NRF_GPIO_PIN_SENSE_LOW);
    nrf_gpio_cfg_sense_input(S31, NRF_GPIO_PIN_PULLUP, NRF_GPIO_PIN_SENSE_LOW);
    nrf_gpio_cfg_sense_input(S32, NRF_GPIO_PIN_PULLUP, NRF_GPIO_PIN_SENSE_LOW);
    nrf_gpio_cfg_sense_input(S33, NRF_GPIO_PIN_PULLUP, NRF_GPIO_PIN_SENSE_LOW);
    nrf_gpio_cfg_sense_input(S34, NRF_GPIO_PIN_PULLUP, NRF_GPIO_PIN_SENSE_LOW);
    nrf_gpio_cfg_sense_input(S41, NRF_GPIO_PIN_PULLUP, NRF_GPIO_PIN_SENSE_LOW);
    nrf_gpio_cfg_sense_input(S42, NRF_GPIO_PIN_PULLUP, NRF_GPIO_PIN_SENSE_LOW);
    nrf_gpio_cfg_sense_input(S43, NRF_GPIO_PIN_PULLUP, NRF_GPIO_PIN_SENSE_LOW);
    nrf_gpio_cfg_sense_input(S44, NRF_GPIO_PIN_PULLUP, NRF_GPIO_PIN_SENSE_LOW);
    nrf_gpio_cfg_sense_input(S45, NRF_GPIO_PIN_PULLUP, NRF_GPIO_PIN_SENSE_LOW);
    nrf_gpio_cfg_sense_input(S51, NRF_GPIO_PIN_PULLUP, NRF_GPIO_PIN_SENSE_LOW);
    nrf_gpio_cfg_sense_input(S52, NRF_GPIO_PIN_PULLUP, NRF_GPIO_PIN_SENSE_LOW);
    nrf_gpio_cfg_sense_input(S53, NRF_GPIO_PIN_PULLUP, NRF_GPIO_PIN_SENSE_LOW);
    nrf_gpio_cfg_sense_input(S54, NRF_GPIO_PIN_PULLUP, NRF_GPIO_PIN_SENSE_LOW);
    nrf_gpio_cfg_sense_input(S55, NRF_GPIO_PIN_PULLUP, NRF_GPIO_PIN_SENSE_LOW);
    nrf_gpio_cfg_sense_input(S61, NRF_GPIO_PIN_PULLUP, NRF_GPIO_PIN_SENSE_LOW);
    nrf_gpio_cfg_sense_input(S62, NRF_GPIO_PIN_PULLUP, NRF_GPIO_PIN_SENSE_LOW);
    nrf_gpio_cfg_sense_input(S63, NRF_GPIO_PIN_PULLUP, NRF_GPIO_PIN_SENSE_LOW);
    nrf_gpio_cfg_sense_input(S64, NRF_GPIO_PIN_PULLUP, NRF_GPIO_PIN_SENSE_LOW);
    nrf_gpio_cfg_sense_input(S65, NRF_GPIO_PIN_PULLUP, NRF_GPIO_PIN_SENSE_LOW);
    nrf_gpio_cfg_sense_input(S71, NRF_GPIO_PIN_PULLUP, NRF_GPIO_PIN_SENSE_LOW);
}

// Return the key states, masked with valid key pins
static uint32_t read_keys(void)
{
    return ~NRF_GPIO->IN & INPUT_MASK;
}

// Assemble packet and send to receiver
static void send_data(void)
{
    data_payload[0] = ((keys & 1<<S11) ? 1:0) << 7 | \
                      ((keys & 1<<S21) ? 1:0) << 6 | \
                      ((keys & 1<<S31) ? 1:0) << 5 | \
                      ((keys & 1<<S41) ? 1:0) << 4 | \
                      ((keys & 1<<S51) ? 1:0) << 3 | \
                      ((keys & 1<<S61) ? 1:0) << 2 | \
                      ((keys & 1<<S12) ? 1:0) << 1 | \
                      ((keys & 1<<S22) ? 1:0) << 0;

    data_payload[1] = ((keys & 1<<S32) ? 1:0) << 7 | \
                      ((keys & 1<<S42) ? 1:0) << 6 | \
                      ((keys & 1<<S52) ? 1:0) << 5 | \
                      ((keys & 1<<S62) ? 1:0) << 4 | \
                      ((keys & 1<<S13) ? 1:0) << 3 | \
                      ((keys & 1<<S23) ? 1:0) << 2 | \
                      ((keys & 1<<S33) ? 1:0) << 1 | \
                      ((keys & 1<<S43) ? 1:0) << 0;

    data_payload[2] = ((keys & 1<<S53) ? 1:0) << 7 | \
                      ((keys & 1<<S63) ? 1:0) << 6 | \
                      ((keys & 1<<S14) ? 1:0) << 5 | \
                      ((keys & 1<<S24) ? 1:0) << 4 | \
                      ((keys & 1<<S34) ? 1:0) << 3 | \
                      ((keys & 1<<S44) ? 1:0) << 2 | \
                      ((keys & 1<<S54) ? 1:0) << 1 | \
                      ((keys & 1<<S64) ? 1:0) << 0;

    data_payload[3] = ((keys & 1<<S45) ? 1:0) << 7 | \
                      ((keys & 1<<S55) ? 1:0) << 6 | \
                      ((keys & 1<<S65) ? 1:0) << 5 | \
                      ((keys & 1<<S71) ? 1:0) << 4 | \
                      0 << 0 | \
                      0 << 0 | \
                      0 << 0 | \
                      0 << 0;
    nrf_gzll_add_packet_to_tx_fifo(PIPE_NUMBER, data_payload, TX_PAYLOAD_LENGTH);
}

// 8Hz held key maintenance, keeping the reciever keystates valid
static void handler_maintenance(nrf_drv_rtc_int_type_t int_type)
{
    send_data();
}

// 1000Hz debounce sampling
static void handler_debounce(nrf_drv_rtc_int_type_t int_type)
{
    // debouncing, waits until there have been no transitions in 5ms (assuming five 1ms ticks)
    if (debouncing)
    {
        // if debouncing, check if current keystates equal to the snapshot
        if (keys_snapshot == read_keys())
        {
            // DEBOUNCE ticks of stable sampling needed before sending data
            debounce_ticks++;
            if (debounce_ticks == DEBOUNCE)
            {
                keys = keys_snapshot;
                send_data();
            }
        }
        else
        {
            // if keys change, start period again
            debouncing = false;
        }
    }
    else
    {
        // if the keystate is different from the last data
        // sent to the receiver, start debouncing
        if (keys != read_keys())
        {
            keys_snapshot = read_keys();
            debouncing = true;
            debounce_ticks = 0;
        }
    }

    // looking for 500 ticks of no keys pressed, to go back to deep sleep
    if (read_keys() == 0)
    {
        activity_ticks++;
        if (activity_ticks > ACTIVITY)
        {
            nrf_drv_rtc_disable(&rtc_maint);
            nrf_drv_rtc_disable(&rtc_deb);
        }
    }
    else
    {
        activity_ticks = 0;
    }

}


// Low frequency clock configuration
static void lfclk_config(void)
{
    nrf_drv_clock_init();

    nrf_drv_clock_lfclk_request(NULL);
}

// RTC peripheral configuration
static void rtc_config(void)
{
    //Initialize RTC instance
    nrf_drv_rtc_init(&rtc_maint, NULL, handler_maintenance);
    nrf_drv_rtc_init(&rtc_deb, NULL, handler_debounce);

    //Enable tick event & interrupt
    nrf_drv_rtc_tick_enable(&rtc_maint,true);
    nrf_drv_rtc_tick_enable(&rtc_deb,true);

    //Power on RTC instance
    //nrf_drv_rtc_enable(&rtc_maint);
    //nrf_drv_rtc_enable(&rtc_deb);
}

int main()
{
    // Initialize Gazell
    nrf_gzll_init(NRF_GZLL_MODE_DEVICE);
    
    // Attempt sending every packet up to 100 times    
    nrf_gzll_set_max_tx_attempts(100);

    // Addressing
    nrf_gzll_set_base_address_0(0x01020304);
    nrf_gzll_set_base_address_1(0x05060708);

    // Enable Gazell to start sending over the air
    nrf_gzll_enable();

    // Configure 32kHz xtal oscillator
    lfclk_config(); 

    // Configure RTC peripherals with ticks
    rtc_config();

    // Configure all keys as inputs with pullups
    gpio_config();

    // Set the GPIOTE PORT event as interrupt source, and enable interrupts for GPIOTE
    NRF_GPIOTE->INTENSET = GPIOTE_INTENSET_PORT_Msk;
    NVIC_EnableIRQ(GPIOTE_IRQn);
    
    /*nrf_gpio_cfg_output(LED_PIN);*/
    /*nrf_gpio_pin_set(LED_PIN);*/
    /*nrf_delay_ms(250);*/
    /*nrf_gpio_pin_clear(LED_PIN);*/
    /*nrf_delay_ms(250);*/
    /*nrf_gpio_pin_set(LED_PIN);*/
    /*nrf_delay_ms(250);*/
    /*nrf_gpio_pin_clear(LED_PIN);*/


    // Main loop, constantly sleep, waiting for RTC and gpio IRQs
    while(1)
    {
        __SEV();
        __WFE();
        __WFE(); 
    }
}

// This handler will be run after wakeup from system ON (GPIO wakeup)
void GPIOTE_IRQHandler(void)
{
    if(NRF_GPIOTE->EVENTS_PORT)
    {
        //clear wakeup event
        NRF_GPIOTE->EVENTS_PORT = 0;

        //enable rtc interupt triggers
        nrf_drv_rtc_enable(&rtc_maint);
        nrf_drv_rtc_enable(&rtc_deb);

        debouncing = false;
        debounce_ticks = 0;
        activity_ticks = 0;
    }
}



/*****************************************************************************/
/** Gazell callback function definitions  */
/*****************************************************************************/

void  nrf_gzll_device_tx_success(uint32_t pipe, nrf_gzll_device_tx_info_t tx_info)
{
    uint32_t ack_payload_length = NRF_GZLL_CONST_MAX_PAYLOAD_LENGTH;    

    if (tx_info.payload_received_in_ack)
    {
        // Pop packet and write first byte of the payload to the GPIO port.
        nrf_gzll_fetch_packet_from_rx_fifo(pipe, ack_payload, &ack_payload_length);
    }
}

// no action is taken when a packet fails to send, this might need to change
void nrf_gzll_device_tx_failed(uint32_t pipe, nrf_gzll_device_tx_info_t tx_info)
{
    
}

// Callbacks not needed
void nrf_gzll_host_rx_data_ready(uint32_t pipe, nrf_gzll_host_rx_info_t rx_info)
{}
void nrf_gzll_disabled()
{}

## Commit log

2017-09-29 added kicad-mitosis
    [mitosis.kicad_pcb, mitosis.sch, receiver.kicad_pcb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]
2017-09-30 cleaned-up renamed to default
    [mitosis.kicad_pcb, mitosis.sch, receiver.kicad_pcb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]
2017-09-30 added default gerbers
2017-10-10 added interphase mod
    [interphase.kicad_pcb, interphase.sch]
2017-10-10 renamed to big-pads
    [mitosis.kicad_pcb, mitosis.sch, receiver.kicad_pcb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]
2018-06-27 started iris outline
    [data.dsn, data.kicad_pcb, data.sch]
2018-07-09 updated readme, added link to Orthus
    [data.dsn]
2018-07-10 added orthrus
    [atreus_split-B.Cu.gbl, atreus_split-B.Mask.gbs, atreus_split-B.SilkS.gbo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]
2018-11-14 added mitosis-laser.dxf
    [mitosis-laser.dxf]
2018-11-16 updated mitosis-laser.dxf (reexported with qcad dxf r14)
    [mitosis-laser.dxf]
